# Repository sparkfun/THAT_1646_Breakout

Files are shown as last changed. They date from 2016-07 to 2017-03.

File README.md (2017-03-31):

SparkFun THAT 1646 Breakout
========================================

THAT-1646 Breakout

[*BOB-14003*](https://www.sparkfun.com/products/14003)

The THAT 1646 OutSmarts Breakout Board offers an easy solution to adding a balanced audio output to your circuits. The THAT OutSmarts technology has been designed as a high-grade analog line driver and offers a low distortion and high common mode rejection in real-world audio applications. Each breakout board combines the THAT 1646 IC, its supporting components and a ¼" TRS (Tip Ring Sleeve) socket. With these powers combined, you will find it very easy to use the output drivers on breadboards and in projects!

The THAT 1646 OutSmarts Breakout and its sibling, the THAT 1206 InGenius Breakout, perform mirror-image signal conversion. While the InGenius is a balanced-to-unbalanced input receiver, this OutSmarts is an unbalanced-to-balanced output driver. We have made sure to break out each pin you need to utilize the OutSmarts board including the unbalanced input (IN), the positive and negative power supply rails (V+, V-) and, of course, ground (GND). Additionally, adjacent to each leg of the socket are test points for the signal (T, R, S) and normal (TN, RN, SN) contacts.

Repository Contents
-------------------

* **/Hardware** - Eagle design files (.brd, .sch)
* **/Production** - Production panel files (.brd)

Documentation
--------------
* **[Hookup Guide](https://learn.sparkfun.com/tutorials/that-ingenuis-and-outsmarts-breakout-hookup-guide)** - Basic hookup guide for the THAT 1206 and 1646 breakouts.
* **[SparkFun Fritzing repo](https://github.com/sparkfun/Fritzing_Parts)** - Fritzing diagrams for SparkFun products.
* **[SparkFun 3D Model repo](https://github.com/sparkfun/3D_Models)** - 3D models of SparkFun products.

Product Versions
----------------
* [BOB-14003](https://www.sparkfun.com/products/14003) - THAT 1646 OutSmarts breakout board.
* [BOB-14002](https://www.sparkfun.com/products/14002) - The companion THAT 1206 InGenius breakout board.

Version History
---------------
* [V1.0 Tag](https://github.com/sparkfun/THAT_1646_Breakout/commit/2f91aec23e70d395754cfb3aa0515f236956341f) - Files as of product launch.

License Information
-------------------

This product is _**open source**_!

Please review the LICENSE.md file for license information.

If you have any questions or concerns on licensing, please contact techsupport@sparkfun.com.

Distributed as-is; no warranty is given.

- Your friends at SparkFun.

_<COLLABORATION CREDIT>_

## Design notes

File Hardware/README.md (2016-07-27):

SparkFun <PRODUCT NAME> Design Files
=====================================

The .sch and .brd files hare are Eagle CAD schematic and PCB design files from SparkFun Electronics.
A freeware version of Eagle can be found [here](http://www.cadsoftusa.com/download-eagle/freeware/).

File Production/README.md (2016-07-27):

SparkFun <PRODUCT NAME> Production Files
=========================================

These are the production files SparkFun uses for printing PCBs.

License Information
-------------------
This product is open source! 

The hardware is released under [Creative Commons ShareAlike 4.0 International](https://creativecommons.org/licenses/by-sa/4.0/).

Please use, reuse, and modify these files as you see fit. Please maintain attribution to SparkFun Electronics and release anything derivative under the same license.

Distributed as-is; no warranty is given.

- Your friends at SparkFun.

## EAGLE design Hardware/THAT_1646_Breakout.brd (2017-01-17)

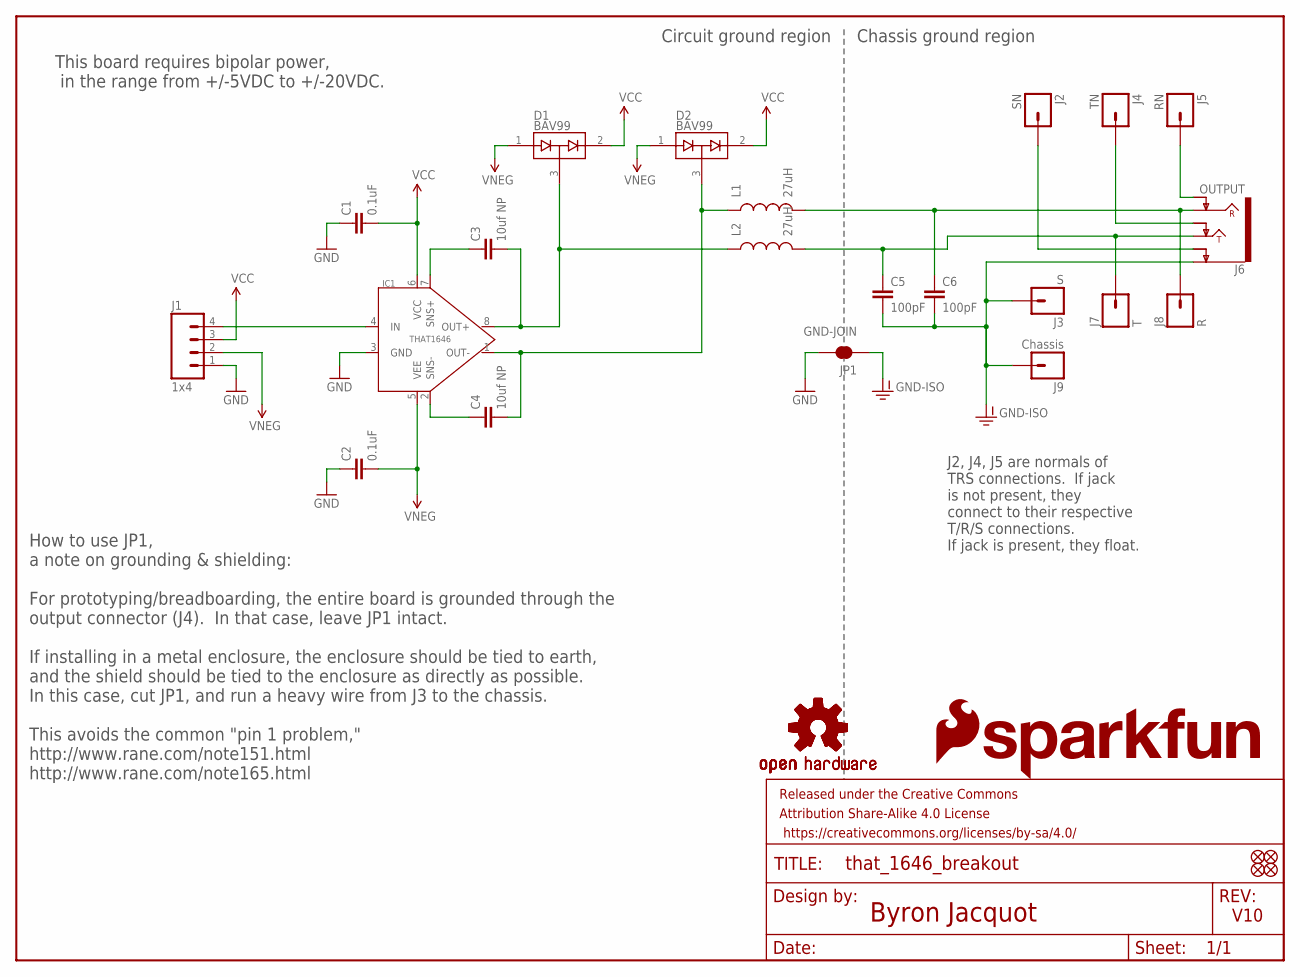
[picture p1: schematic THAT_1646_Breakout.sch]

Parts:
C1, C2: 0.1uF; 0603-CAP
C3, C4: 10uf NP; PANASONIC_D
C5, C6: 100pF; 0603-CAP
D1, D2: BAV99; SOT23-3
FD1, FD2, FD3, FD4: FIDUCIALUFIDUCIAL; MICRO-FIDUCIAL
FRAME1: FRAME-LETTER; CREATIVE_COMMONS
IC1: THAT1646; SO08
J1: 1x4; 1X04_NO_SILK_ALL_ROUND
J2: SN; 1X01_NO_SILK
J3: S; 1X01_NO_SILK
J4: TN; 1X01_NO_SILK
J5: RN; 1X01_NO_SILK
J6: OUTPUT; AUDIO_JACK_0.25"_TRS_PTH_RA
J7: T; 1X01_NO_SILK
J8: R; 1X01_NO_SILK
J9: Chassis; 1X01_NO_SILK
JP1: GND-JOIN; PAD-JUMPER-2-NC_BY_TRACE_YES_SILK
L1, L2: 27uH; 0603
LOGO1, LOGO2: OSHW-LOGOS; OSHW-LOGO-S
LOGO4: SFE_LOGO_FLAME.2_INCH; SFE_LOGO_FLAME_.2
LOGO5: SFE_LOGO_NAME.1_INCH; SFE_LOGO_NAME_.1

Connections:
GND: C1.1, C2.1, IC1.3 (GND), J1.1, JP1.2
GND-ISO: C5.2, C6.2, J3.1, J6.SLEEVE (EARTH), J9.1, JP1.1
unnamed: J5.1, J6.RING-NORM
unnamed: J4.1, J6.TIP-NORM
unnamed: J2.1, J6.SLEEVE-NORM (EARTH-NORM)
unnamed: C5.1, J6.TIP, J7.1, L2.2
unnamed: C6.1, J6.RING, J8.1, L1.2
unnamed: C3.- (2), D1.3 (COM), IC1.8 (OUT+), L2.1
unnamed: C4.- (2), D2.3 (COM), IC1.1 (OUT-), L1.1
unnamed: C4.+ (1), IC1.2 (SNS-)
unnamed: C3.+ (1), IC1.7 (SNS+)
unnamed: IC1.4 (IN), J1.4
VCC: C1.2, D1.2 (C2), D2.2 (C2), IC1.6 (VCC), J1.3
VNEG: C2.2, D1.1 (A1), D2.1 (A1), IC1.5 (VEE), J1.2

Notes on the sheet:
Byron Jacquot
V10
Chassis ground region
Circuit ground region
How to use JP1, a note on grounding & shielding: For prototyping/breadboarding, the entire board is grounded through the output connector (J4). In that case, leave JP1 intact. If installing in a metal enclosure, the enclosure should be tied to earth, and the shield should be tied to the enclosure a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
This board requires bipolar power, in the range from +/-5VDC to +/-20VDC.
J2, J4, J5 are normals of TRS connections. If jack is not present, they connect to their respective T/R/S connections. If jack is present, they float.

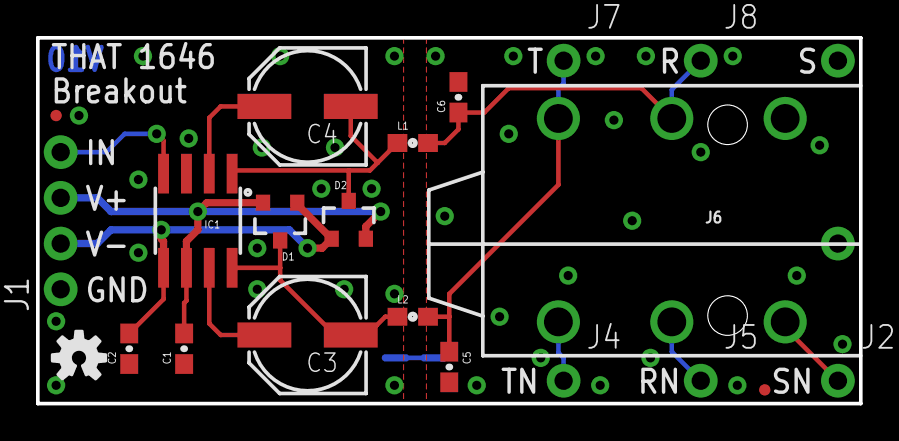
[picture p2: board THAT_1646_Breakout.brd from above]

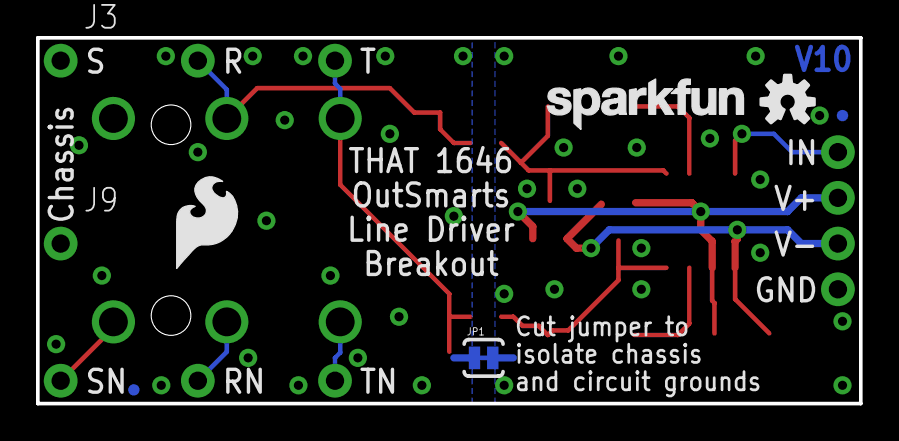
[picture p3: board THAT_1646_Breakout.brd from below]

Board: 2 copper layers, 45.7 x 20.3 mm, 30 parts (8 on the bottom side), 14 nets.

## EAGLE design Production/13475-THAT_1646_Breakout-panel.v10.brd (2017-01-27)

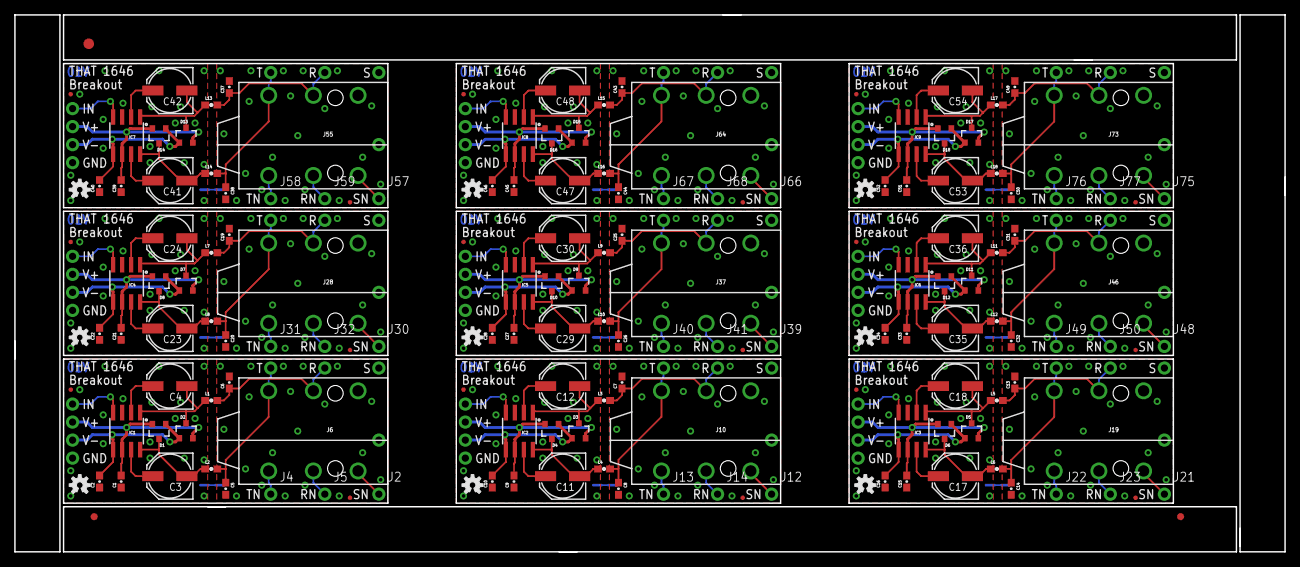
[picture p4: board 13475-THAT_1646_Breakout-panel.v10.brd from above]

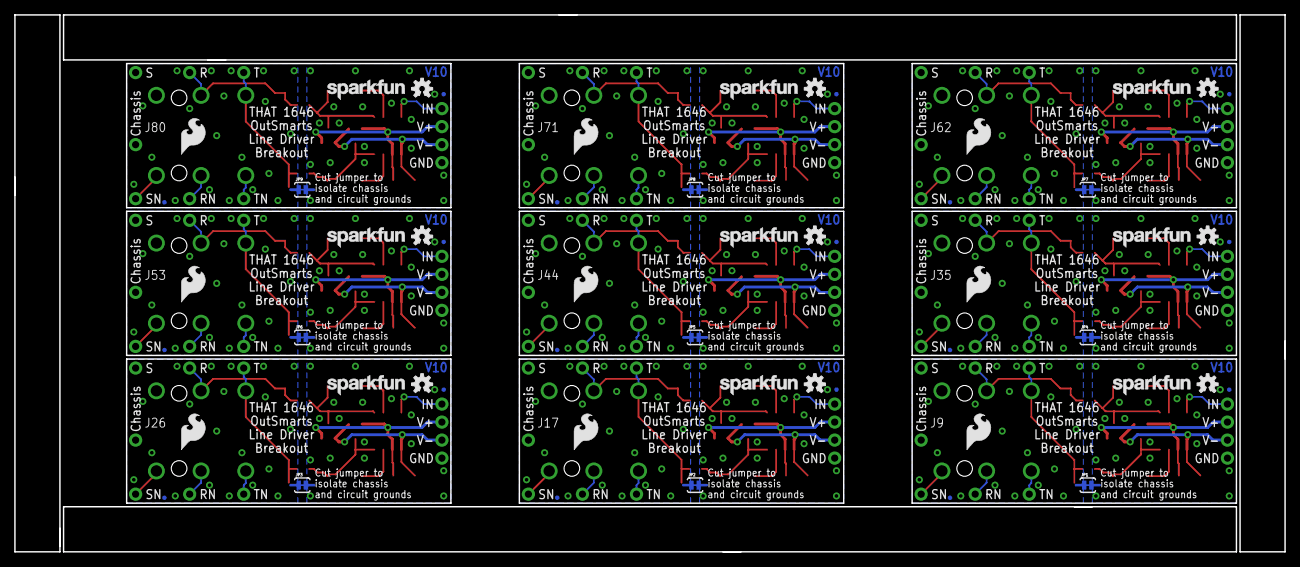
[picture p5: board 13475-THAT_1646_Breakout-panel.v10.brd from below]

Board: 2 copper layers, 179.1 x 75.7 mm, 264 parts (72 on the bottom side), 126 nets.

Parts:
C1, C2, C9, C10, C15, C16, C21, C22, C27, C28, C33, C34, C39, C40, C45, C46, C51, C52: 0.1uF; 0603-CAP
C3, C4, C11, C12, C17, C18, C23, C24, C29, C30, C35, C36, C41, C42, C47, C48, C53, C54: 10uf NP; PANASONIC_D
C5, C6, C7, C8, C13, C14, C19, C20, C25, C26, C31, C32, C37, C38, C43, C44, C49, C50: 100pF; 0603-CAP
D1, D2, D3, D4, D5, D6, D7, D8, D9, D10, D11, D12, D13, D14, D15, D16, D17, D18: BAV99; SOT23-3
E$1: FIDUCIAL-1.5X3
E$3, E$4: FIDUCIAL-1X2
FD1, FD2, FD3, FD4, FD5, FD6, FD7, FD8, FD9, FD10, FD11, FD12, FD13, FD14, FD15, FD16, FD17, FD18, FD19, FD20, FD21, FD22, FD23, FD24, FD25, FD26, FD27, FD28, FD29, FD30, FD31, FD32, FD33, FD34, FD35, FD36: FIDUCIALUFIDUCIAL; MICRO-FIDUCIAL
IC1, IC2, IC3, IC4, IC5, IC6, IC7, IC8, IC9: THAT1646; SO08
J1, J11, J20, J29, J38, J47, J56, J65, J74: 1x4; 1X04_NO_SILK_ALL_ROUND
J2, J12, J21, J30, J39, J48, J57, J66, J75: SN; 1X01_NO_SILK
J3, J18, J27, J36, J45, J54, J63, J72, J81: S; 1X01_NO_SILK
J4, J13, J22, J31, J40, J49, J58, J67, J76: TN; 1X01_NO_SILK
J5, J14, J23, J32, J41, J50, J59, J68, J77: RN; 1X01_NO_SILK
J6, J10, J19, J28, J37, J46, J55, J64, J73: OUTPUT; AUDIO_JACK_0.25"_TRS_PTH_RA
J7, J15, J24, J33, J42, J51, J60, J69, J78: T; 1X01_NO_SILK
J8, J16, J25, J34, J43, J52, J61, J70, J79: R; 1X01_NO_SILK
J9, J17, J26, J35, J44, J53, J62, J71, J80: Chassis; 1X01_NO_SILK
JP1, JP2, JP3, JP4, JP5, JP6, JP7, JP8, JP9: GND-JOIN; PAD-JUMPER-2-NC_BY_TRACE_YES_SILK
L1, L2, L3, L4, L5, L6, L7, L8, L9, L10, L11, L12, L13, L14, L15, L16, L17, L18: 27uH; 0603
LOGO1, LOGO2, LOGO6, LOGO7, LOGO10, LOGO11, LOGO14, LOGO15, LOGO18, LOGO19, LOGO22, LOGO23, LOGO26, LOGO27, LOGO30, LOGO31, LOGO34, LOGO35: OSHW-LOGOS; OSHW-LOGO-S
LOGO3, LOGO5, LOGO9, LOGO13, LOGO17, LOGO21, LOGO25, LOGO29, LOGO33: SFE_LOGO_NAME.1_INCH; SFE_LOGO_NAME_.1
LOGO4, LOGO8, LOGO12, LOGO16, LOGO20, LOGO24, LOGO28, LOGO32, LOGO36: SFE_LOGO_FLAME.2_INCH; SFE_LOGO_FLAME_.2

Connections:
GND: C1.1, C2.1, IC1.3, J1.1, JP1.2
GND1: C9.1, C10.1, IC2.3, J11.1, JP2.2
GND2: C15.1, C16.1, IC3.3, J20.1, JP3.2
GND3: C21.1, C22.1, IC4.3, J29.1, JP4.2
GND4: C27.1, C28.1, IC5.3, J38.1, JP5.2
GND5: C33.1, C34.1, IC6.3, J47.1, JP6.2
GND6: C39.1, C40.1, IC7.3, J56.1, JP7.2
GND7: C45.1, C46.1, IC8.3, J65.1, JP8.2
GND8: C51.1, C52.1, IC9.3, J74.1, JP9.2
GND-ISO: C5.2, C6.2, J3.1, J6.SLEEVE, J9.1, JP1.1
GND-ISO1: C7.2, C8.2, J10.SLEEVE, J17.1, J18.1, JP2.1
GND-ISO2: C13.2, C14.2, J19.SLEEVE, J26.1, J27.1, JP3.1
GND-ISO3: C19.2, C20.2, J28.SLEEVE, J35.1, J36.1, JP4.1
GND-ISO4: C25.2, C26.2, J37.SLEEVE, J44.1, J45.1, JP5.1
GND-ISO5: C31.2, C32.2, J46.SLEEVE, J53.1, J54.1, JP6.1
GND-ISO6: C37.2, C38.2, J55.SLEEVE, J62.1, J63.1, JP7.1
GND-ISO7: C43.2, C44.2, J64.SLEEVE, J71.1, J72.1, JP8.1
GND-ISO8: C49.2, C50.2, J73.SLEEVE, J80.1, J81.1, JP9.1
unnamed: J5.1, J6.RING-NORM
unnamed: J4.1, J6.TIP-NORM
unnamed: J2.1, J6.SLEEVE-NORM
unnamed: C8.1, J10.TIP, J15.1, L4.2
unnamed: C7.1, J10.RING, J16.1, L3.2
unnamed: C11.-, D4.3, IC2.8, L4.1
unnamed: C12.-, D3.3, IC2.1, L3.1
unnamed: C5.1, J6.TIP, J7.1, L2.2
unnamed: C6.1, J6.RING, J8.1, L1.2
unnamed: C3.-, D1.3, IC1.8, L2.1
unnamed: C4.-, D2.3, IC1.1, L1.1
unnamed: C12.+, IC2.2
unnamed: C4.+, IC1.2
unnamed: C3.+, IC1.7
unnamed: C11.+, IC2.7
unnamed: IC1.4, J1.4
unnamed: IC2.4, J11.4
unnamed: J10.RING-NORM, J14.1
unnamed: J10.TIP-NORM, J13.1
unnamed: J10.SLEEVE-NORM, J12.1
unnamed: C14.1, J19.TIP, J24.1, L6.2
unnamed: C13.1, J19.RING, J25.1, L5.2
unnamed: C17.-, D6.3, IC3.8, L6.1
unnamed: C18.-, D5.3, IC3.1, L5.1
unnamed: C18.+, IC3.2
unnamed: C17.+, IC3.7
unnamed: IC3.4, J20.4
unnamed: J19.RING-NORM, J23.1
unnamed: J19.TIP-NORM, J22.1
unnamed: J19.SLEEVE-NORM, J21.1
unnamed: C20.1, J28.TIP, J33.1, L8.2
unnamed: C19.1, J28.RING, J34.1, L7.2
unnamed: C23.-, D8.3, IC4.8, L8.1
unnamed: C24.-, D7.3, IC4.1, L7.1
unnamed: C24.+, IC4.2
unnamed: C23.+, IC4.7
unnamed: IC4.4, J29.4
unnamed: J28.RING-NORM, J32.1
unnamed: J28.TIP-NORM, J31.1
unnamed: J28.SLEEVE-NORM, J30.1
unnamed: C26.1, J37.TIP, J42.1, L10.2
unnamed: C25.1, J37.RING, J43.1, L9.2
unnamed: C29.-, D10.3, IC5.8, L10.1
unnamed: C30.-, D9.3, IC5.1, L9.1
unnamed: C30.+, IC5.2
unnamed: C29.+, IC5.7
unnamed: IC5.4, J38.4
unnamed: J37.RING-NORM, J41.1
unnamed: J37.TIP-NORM, J40.1
unnamed: J37.SLEEVE-NORM, J39.1
unnamed: C32.1, J46.TIP, J51.1, L12.2
unnamed: C31.1, J46.RING, J52.1, L11.2
unnamed: C35.-, D12.3, IC6.8, L12.1
unnamed: C36.-, D11.3, IC6.1, L11.1
unnamed: C36.+, IC6.2
unnamed: C35.+, IC6.7
unnamed: IC6.4, J47.4
unnamed: J46.RING-NORM, J50.1
unnamed: J46.TIP-NORM, J49.1
unnamed: J46.SLEEVE-NORM, J48.1
unnamed: C38.1, J55.TIP, J60.1, L14.2
unnamed: C37.1, J55.RING, J61.1, L13.2
unnamed: C41.-, D14.3, IC7.8, L14.1
unnamed: C42.-, D13.3, IC7.1, L13.1
unnamed: C42.+, IC7.2
unnamed: C41.+, IC7.7
unnamed: IC7.4, J56.4
unnamed: J55.RING-NORM, J59.1
unnamed: J55.TIP-NORM, J58.1
unnamed: J55.SLEEVE-NORM, J57.1
unnamed: C44.1, J64.TIP, J69.1, L16.2
unnamed: C43.1, J64.RING, J70.1, L15.2
unnamed: C47.-, D16.3, IC8.8, L16.1
unnamed: C48.-, D15.3, IC8.1, L15.1
unnamed: C48.+, IC8.2
unnamed: C47.+, IC8.7
unnamed: IC8.4, J65.4
unnamed: J64.RING-NORM, J68.1
unnamed: J64.TIP-NORM, J67.1
unnamed: J64.SLEEVE-NORM, J66.1
unnamed: C50.1, J73.TIP, J78.1, L18.2
unnamed: C49.1, J73.RING, J79.1, L17.2
unnamed: C53.-, D18.3, IC9.8, L18.1
unnamed: C54.-, D17.3, IC9.1, L17.1
unnamed: C54.+, IC9.2
unnamed: C53.+, IC9.7
unnamed: IC9.4, J74.4
unnamed: J73.RING-NORM, J77.1
unnamed: J73.TIP-NORM, J76.1
unnamed: J73.SLEEVE-NORM, J75.1
VCC: C1.2, D1.2, D2.2, IC1.6, J1.3
VCC1: C9.2, D3.2, D4.2, IC2.6, J11.3
VCC2: C15.2, D5.2, D6.2, IC3.6, J20.3
VCC3: C21.2, D7.2, D8.2, IC4.6, J29.3
VCC4: C27.2, D9.2, D10.2, IC5.6, J38.3
VCC5: C33.2, D11.2, D12.2, IC6.6, J47.3
VCC6: C39.2, D13.2, D14.2, IC7.6, J56.3
VCC7: C45.2, D15.2, D16.2, IC8.6, J65.3
VCC8: C51.2, D17.2, D18.2, IC9.6, J74.3
VNEG: C2.2, D1.1, D2.1, IC1.5, J1.2
VNEG1: C10.2, D3.1, D4.1, IC2.5, J11.2
VNEG2: C16.2, D5.1, D6.1, IC3.5, J20.2
VNEG3: C22.2, D7.1, D8.1, IC4.5, J29.2
VNEG4: C28.2, D9.1, D10.1, IC5.5, J38.2
VNEG5: C34.2, D11.1, D12.1, IC6.5, J47.2
VNEG6: C40.2, D13.1, D14.1, IC7.5, J56.2
VNEG7: C46.2, D15.1, D16.1, IC8.5, J65.2
VNEG8: C52.2, D17.1, D18.1, IC9.5, J74.2

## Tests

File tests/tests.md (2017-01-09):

# THAT 1646 ests Performed.

## Single-ended output.

__Setup__:

* THAT 1646 powered from +/- 12VDC
* 5Vpp, 500 Hz sine wave applied to board input.
* Oscilloscope watching + & - outputs (tip & ring)

__Method__:

With outputs otherwise floating, verify that differential signals are each 5Vpp.

Then short ring to ground.  Tip should double in amplitude, supply current shouldn't change discernibly.  Remove short.

Short tip to ground.  Ring should double in amplitude, supply current shouldn't change discernibly. Remove short.

## Short circuit current/ output protection.

__Repeat previous setup.__

__Method__:

Short both outputs to ground.  Verify that supply current maxes at less than 70 mA.

(DUT measured 60 mA on either rail, 0 mA ground current)

## Output Clamp Verification.

__Setup__:

__Method__:

Apply 10 mSec +10V pulse to tip.  Observe voltage at tip & pin 8 -- it should be clamped to approx 6.4V.  

Continue observing, and vary positive supply rail slowly upwards from 5 VDC to 20 VDC.  When supply reaches approx 12 VDC, clamping action should disappear.

Repeat for ring & pin 1.

Repeat all above, verifying -10VDC pulses on tip and ring are clamped to lower supply rail.

## Output DC Offset

__Setup:__

* THAT 1646 powered from +/-12 VDC.
* THAT board input shorted to ground.

__Method:__

Use voltmeter to observe DC values from tip to sleeve and ring to sleeve.

(DUT measured +1 mV at tip, -1 mV at ring.)

## Distortion Levels

__Setup:__

__Method:__

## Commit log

2016-07-27 Moving in 1646 files.
    They were previously in the 1206 repo.
    [THAT_1646_Breakout.brd, THAT_1646_Breakout.sch]
2016-07-27 Routed board.
    Worked through initial checklist.
    [THAT_1646_Breakout.brd, THAT_1646_Breakout.sch]
2016-08-08 Post-review updates.
    [THAT_1646_Breakout.brd, THAT_1646_Breakout.sch]
2016-08-09 Updates from engineering checklist.
    [THAT_1646_Breakout.brd, THAT_1646_Breakout.sch]
2016-08-09 Addressing Kade's checklist issues.
    -Via under "THAT" in top silk
    -Nixing "Toed"
    -90-deg trace on bottom made 45.
    -Moved chassis connection out from under TRS.
    [THAT_1646_Breakout.brd, THAT_1646_Breakout.sch]
2016-08-09 One last checklist issue.
    [THAT_1646_Breakout.brd]
2017-01-09 Adding testpoints on T/R/S connections.
    [THAT_1646_Breakout.brd, THAT_1646_Breakout.sch]
2017-01-09 Moving PTH holes to 0.1 grid.
    [THAT_1646_Breakout.brd]
2017-01-16 Updates after group review.
    -Chassis ground pad moved away from selective solder runout.
    -Version numbers fixed.
    -Top/bottom fiducials co-located.
    -Flame oriented to match text.
    [THAT_1646_Breakout.brd, THAT_1646_Breakout.sch]
2017-01-17 Updates from engineering checklist.
    Found too-narrow silk in some packages.
    [THAT_1646_Breakout.sch]
2017-01-17 Engineering checklist updates.
    Found too narrow silk in some packages.
    Moves a couple vias out from under silk text.
    [THAT_1646_Breakout.brd]
2017-03-31 Fixing grounding note in schem.
    J9 is the pad to use for chassis ground. It was incorrectly notated as
    J3.
    [THAT_1646_Breakout.sch]

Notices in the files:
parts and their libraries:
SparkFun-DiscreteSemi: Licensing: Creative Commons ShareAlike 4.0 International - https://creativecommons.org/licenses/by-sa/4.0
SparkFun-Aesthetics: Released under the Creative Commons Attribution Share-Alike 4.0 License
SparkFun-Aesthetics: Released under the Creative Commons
